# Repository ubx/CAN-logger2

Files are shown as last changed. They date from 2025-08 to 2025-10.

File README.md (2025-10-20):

# ESP32 CAN Logger for CANaerospace with WiFi File Browser

This project implements a **dual-mode ESP32 application** for capturing and storing CAN bus data onto an SD card, \
while also providing a temporary WiFi access point with a web-based file browser to retrieve logged data.

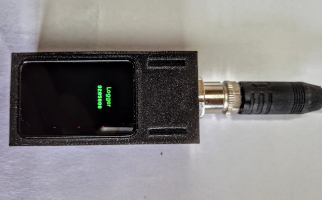
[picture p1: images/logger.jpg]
Logger CAN Logger

---

## Features

### WiFi File Browser
- **WiFi SoftAP Setup** with WPA/WPA2 authentication.
- **Dynamic SSID Generation** based on ESP32 MAC address.
- **Web-based File Browser**:
  - Displays SD card files in a clean HTML table.
  - Supports file size display in human-readable format (KB, MB, GB).
  - Click-to-download functionality with MIME type detection.
- **Automatic Session Timeout**
  - Tracks last HTTP activity.
  - Shuts down after configurable inactivity time.
---

### CAN Logging System
- **CAN Bus Support (TWAI Driver)**
  - Configured for **500 kbit/s**.
  - Accepts all CAN frames.
  - Reliable driver startup with retry on failure.
- **SD Card Logging**
  - Files named sequentially as `CANxxxxx.LOG`.
  - Automatic **old file cleanup** if free space < 2 GB (reclaims up to 4 GB).
  - Efficient batch writes with **32 KB buffering**.
  - Uses `fsync()` to ensure data integrity.
- **Logging Format**
  - Each CAN frame stored as:
    ```
    (timestamp) can <ID>#<DATA>
    ```  
    Example:
    ```
    (1755839938.123456) can 123#11AAFF
    ```
- **Task-based Architecture**
  - `CAN_RX Task`: Receives frames from TWAI driver.
  - `CAN_Proc Task`: Formats messages into log lines.
  - `SD_Writer Task`: Buffers and writes batches to SD card.
- **Runtime Monitoring**
  - Tracks total message count.
  - Periodic logging of statistics to console.

---

## Technical Highlights
- **FreeRTOS Queues** for decoupled CAN reception and SD writing.
- **High-throughput SD logging** using buffered I/O.
- **Failsafe Storage Management** with automatic cleanup.
- **Lightweight Web Server** (ESP-IDF HTTPD) for SD browsing and downloads.
- **No RTC dependency**: Uses a fictional start timestamp to emulate Unix time.
- **Tested on an ESP32-S3 board:** [ESP32-S3 1.64inch AMOLED Touch Display Development Board](https://www.waveshare.com/esp32-s3-touch-amoled-1.64.htm) with a SANDISK Ultra \
  64 GB, microSDXC, U1, UHS-I.
- **Performance Test**: Running `cangen can0 -D i -I i -L 4 -g 0.5` resulted in a transmission rate of \
approximately 1,800 messages per second.
- **Power consumption**: Web server: 473 mW; Logger with display on: 420 mW; Logger with display off: 440 mW.
---

## Typical Use Case
1. **Power up device** → ESP32 starts in **WiFi AP mode** with SD card accessible via browser.
2. **Download / inspect past CAN logs** through the web interface.
3. **After inactivity timeout** → Device switches into **logging mode**, continuously recording
4. CAN traffic onto the SD card.

---

## Pin-to-Pin Wiring Table

| ESP32 Pin | Function | Connected To | Notes |
|---|---|---|---|
| GPIO1 | SPI MOSI | SD Card MOSI | Data out from ESP32 → SD |
| GPIO3 | SPI MISO | SD Card MISO | Data in from SD → ESP32 |
| GPIO2 | SPI SCLK | SD Card SCLK | SPI clock |
| GPIO41 | SPI CS | SD Card CS | Chip select |
| GPIO9 | CS | LCD Chip Select | Active low |
| GPIO10 | PCLK | LCD SPI Clock / Pixel Clock | QSPI clock |
| GPIO11 | DATA0 | LCD Data 0 (D0) | QSPI data line |
| GPIO12 | DATA1 | LCD Data 1 (D1) | QSPI data line |
| GPIO13 | DATA2 | LCD Data 2 (D2) | QSPI data line |
| GPIO14 | DATA3 | LCD Data 3 (D3) | QSPI data line |
| GPIO21 | RST | LCD Reset | Optional, active low 
| GPIO18 | CAN TX | CAN Transceiver TXD | Transmit to CAN bus |
| GPIO17 | CAN RX | CAN Transceiver RXD | Receive from CAN bus |
| 3V3 | Power | SD Card VCC, CAN VCC | Ensure 3.3V compatible |
| GND | Ground | SD Card GND, CAN GND | Common ground reference |
| CANH/— | — | CAN Bus High Line | Differential bus line |
| CANL/— | — | CAN Bus Low Line | Differential bus line |

## Recommended Parts List

### Core Components
- **ESP32 Development Board**
  - Example: ESP32-DevKitC, ESP32-WROOM, or M5Stack Core (if display/UI desired)
  - Must expose SPI pins and GPIOs used in the project

- **SD Card Module (SPI interface)**
  - Example: MicroSD Card Module (3.3V logic, SPI mode support)
  - Ensure 3.3V compatible (no 5V modules without level shifting)
  - MicroSD card, Class 10, A1 or higher, ≥16 GB recommended

- **CAN Transceiver** (connects ESP32 to CAN bus)
  - Example ICs:
    - SN65HVD230 (3.3V, commonly used with ESP32)
    - MCP2551 (5V, requires level shifting for ESP32)
    - TJA1050 (5V, also requires level shifting)
  - Choose based on bus voltage (3.3V-friendly parts are easier)

### Power & Connectivity
- **Stable 5V Supply** (for ESP32 board)
  - ESP32 boards usually regulate down to 3.3V internally
- **Common Ground Reference** between ESP32, SD card, and CAN transceiver
- **CAN Bus Wiring**
  - Twisted pair cable (for CANH & CANL)
  - 120 Ω termination resistors at both bus ends

### Optional / Helpful
- **MicroSD Card Reader** (for PC, to inspect logs directly if needed)
- **USB-to-CAN Adapter** (for testing/logging against a PC CAN interface)
- **Case/Enclosure** to protect the ESP32 + modules in automotive environment
- **For CANaerospace logs**: use [this program](https://github.com/ubx/canlog-correct-ts/blob/master/correct-ts.py) to adjust timestamps.
- **Format SD card**: use [this tool](https://www.sdcard.org/downloads/sd-memory-card-formatter-for-linux/)

### Bill of materials

| Number | Part | Qty | Picture | 	Source |
|---|---|-----|---|---|
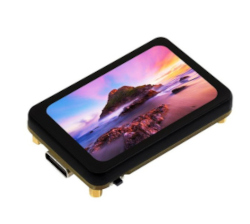
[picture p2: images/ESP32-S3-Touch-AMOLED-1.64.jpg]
| 1 | ESP32-S3 1.64inch AMOLED<br/> Touch Display Development Board | 1 |   | [AMOLED Touch Display<br/>Development Board](https://www.waveshare.com/esp32-s3-touch-amoled-1.64.htm) | 
| 2 | SN65HVD230 CAN Board | 1 | Board | [SN65HVD230 CAN Board	](https://www.waveshare.com/sn65hvd230-can-board.htm) | |
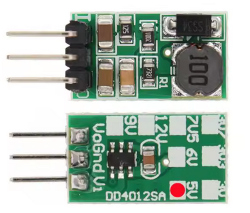
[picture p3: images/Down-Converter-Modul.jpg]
| 3 | Step Down Converter Modul | 1 |  | [Step Down Converter Modul	](https://de.aliexpress.com/item/1005006461126809.html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) |
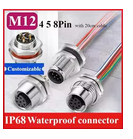
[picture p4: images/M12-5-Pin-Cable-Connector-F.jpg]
| 4 | M12 5 Pin Cable Connector | 1 |  | [M12 5 Pin Cable Connector](https://de.aliexpress.com/item/1005008983446794.html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)  |
| 5 | micro sd card | 1 | Board |
| 6 | M2x5 round screw | 4 | | |
| 7 | M2.5x5 countersunk screw | 1 |
| 8 | M2.5x4 insert | 1 |
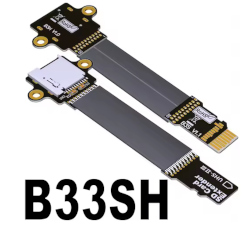
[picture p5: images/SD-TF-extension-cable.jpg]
| 9 | Optional:<br/>SD-TF-extension-cable | 1 |  | [SD-TF-extension-cable	](https://de.aliexpress.com/item/1005005671622003.html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) |

---

## Troubleshooting: sdQueue full / canQueue full warnings
If you see warnings like:
- W (xxxx) CAN_Proc: sdQueue full, dropped line
- W (xxxx) CAN_RX: canQueue full, dropped

it means the producer tasks (CAN reception/formatting) are temporarily faster than the consumer (SD writer). \
The firmware includes several mitigations:

Additional steps you can take
- Use a fast SD card (A1/A2 or High Endurance) and keep it healthy/formatted (FAT32).
- Reduce other workload while logging (disable unnecessary peripherals, WiFi, or display if not needed).
- If you still experience drops, you can increase queue depths in src/logger/logging.cpp:
  - CAN_QUEUE_LEN: number of CAN frame buffered between driver and formatter.
  - SD_QUEUE_LEN: number of formatted lines buffered before SD writing.
    Be mindful that increasing these consumes internal RAM.
- If your board has PSRAM, keep it enabled. The logger uses a large batch buffer to write in big chunks for higher throughput.
- Ensure stable 3.3 V supply. Brownouts can slow peripherals and the filesystem.

Notes
- Even with a high-rate CAN traffic (e.g., ~1200 msgs/s), a proper SD card and power supply should avoid drops in most cases.
- If absolute losslessness is required, consider reducing CAN bus load, increasing queue sizes, or writing in binary \
to reduce per-message overhead.

## Todo
- Check display z-distance.
- PCB, move modules up 2mm z-distance.
- PCB, bigger holes for CAN connector cables.
- Check usb hole, make it more tolerant.
- Better lid locking.

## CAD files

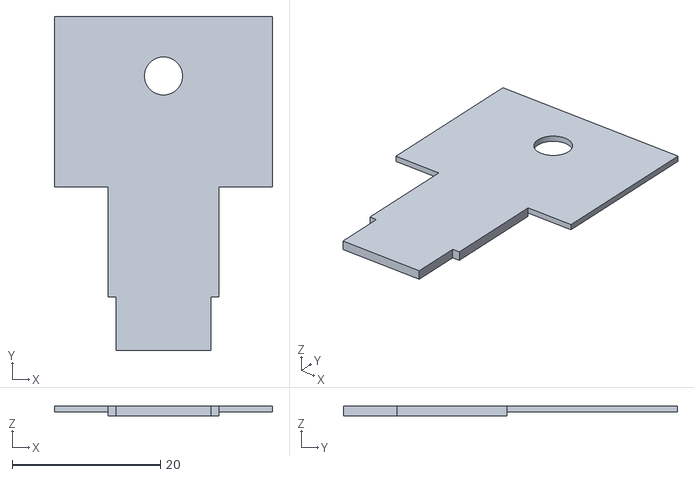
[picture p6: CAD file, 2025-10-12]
case/lid-sdcard-negative-3.stl
29.4 x 45.0 x 1.30

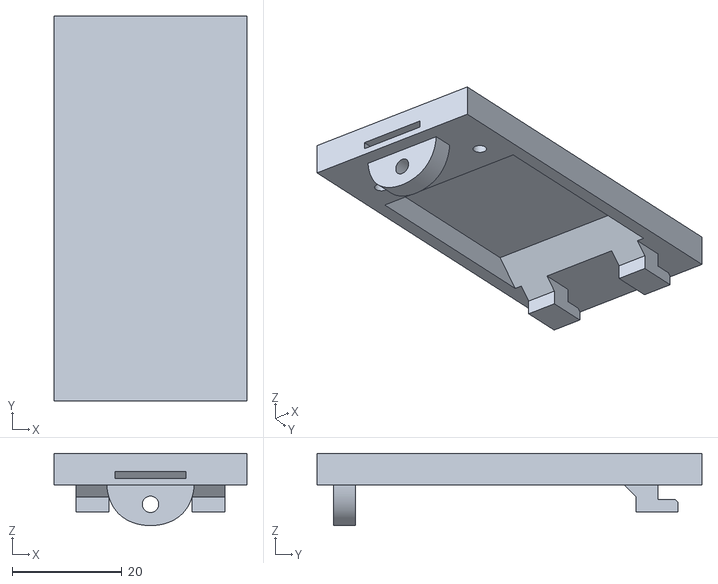
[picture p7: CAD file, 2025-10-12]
case/lid-sdcard.stl
35.1 x 70.2 x 13.2

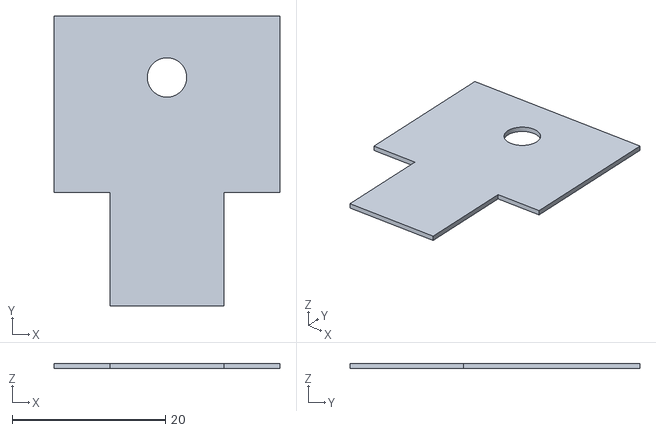
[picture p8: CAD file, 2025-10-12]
case/lid-sdcard-negative-2.stl
29.4 x 37.8 x 0.7

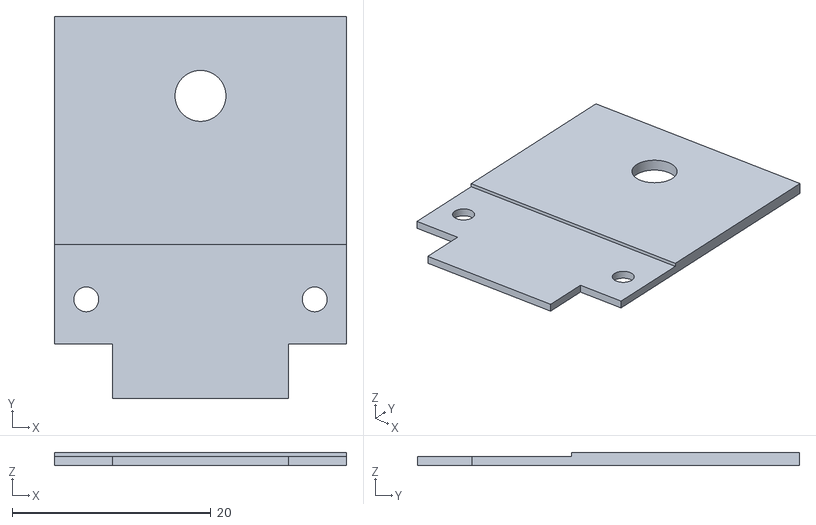
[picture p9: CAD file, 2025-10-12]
case/lid-sdcard-negative-1.stl
29.4 x 38.5 x 1.30

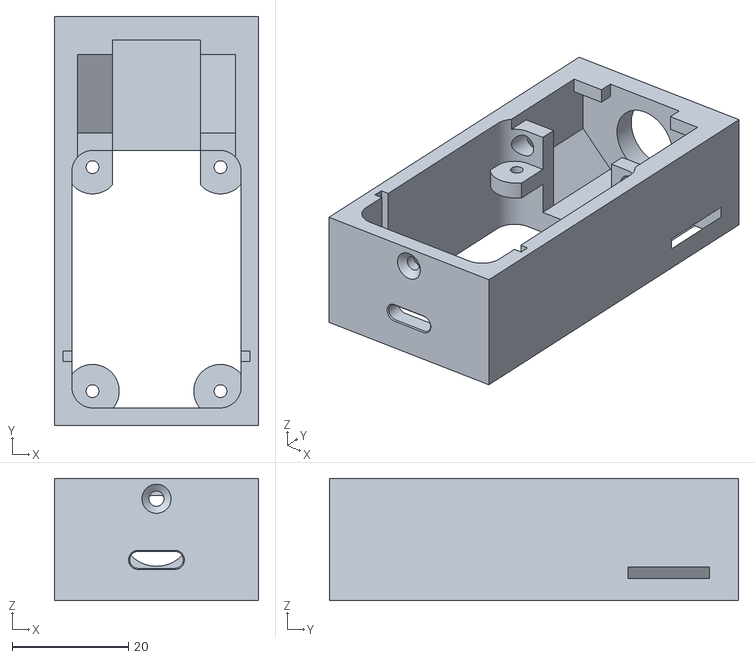
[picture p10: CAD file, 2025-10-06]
case/case.stl
35.1 x 70.3 x 21.0

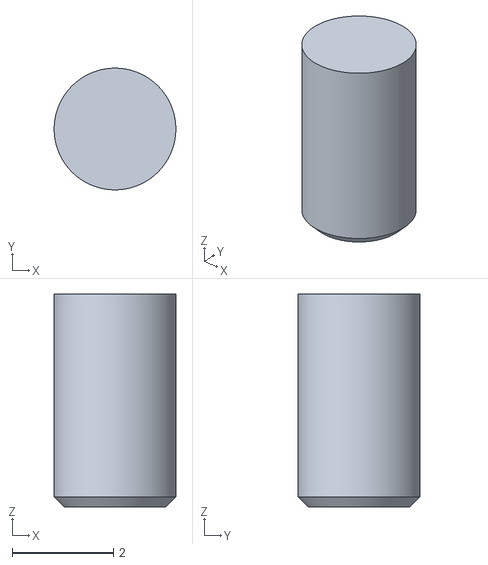
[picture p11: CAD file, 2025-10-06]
case/cones.stl
2.40 x 2.40 x 4.20

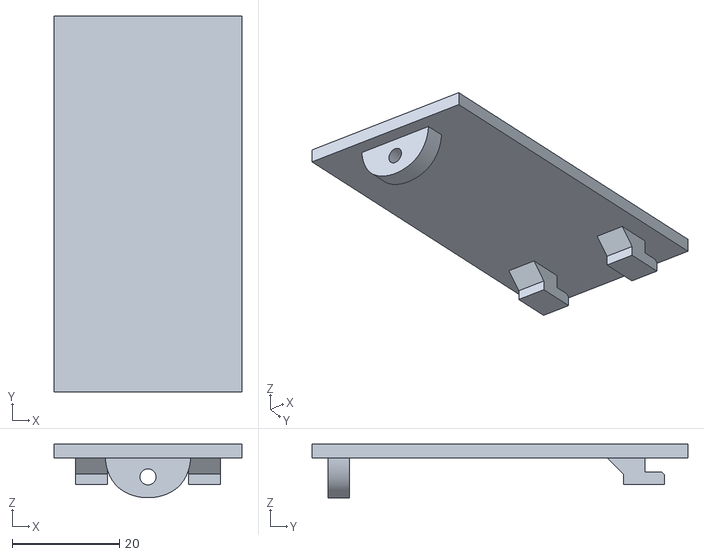
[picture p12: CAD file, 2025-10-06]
case/lid.stl
35.1 x 70.2 x 10.00

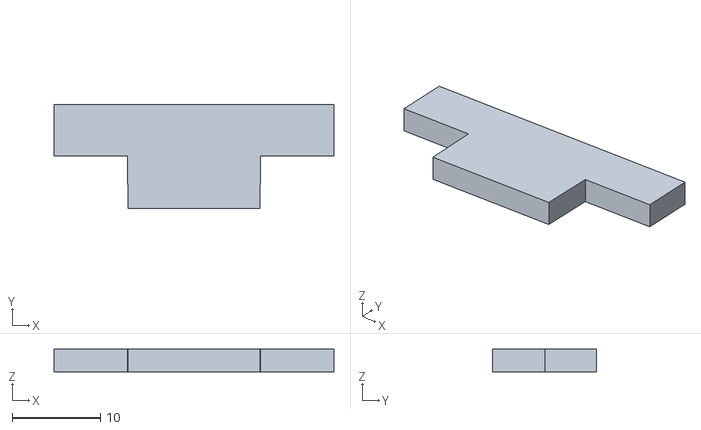
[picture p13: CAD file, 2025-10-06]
case/lid-sdcard-negative-4.stl
31.8 x 11.8 x 2.60

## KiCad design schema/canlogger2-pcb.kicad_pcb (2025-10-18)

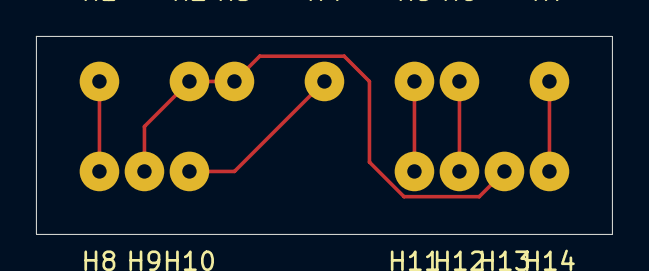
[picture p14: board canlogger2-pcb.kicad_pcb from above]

Board: 2 copper layers, 32.0 x 11.0 mm, 14 parts (0 on the bottom side), 6 nets.

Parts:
H1: 5V; ConnectingHole_0.8mm_M2_DIN965_Pad
H2, H3, H9, H13: GND; ConnectingHole_0.8mm_M2_DIN965_Pad
H4: 12V; ConnectingHole_0.8mm_M2_DIN965_Pad
H5: Tx; ConnectingHole_0.8mm_M2_DIN965_Pad
H6: Rx; ConnectingHole_0.8mm_M2_DIN965_Pad
H7, H14: 3.3V; ConnectingHole_0.8mm_M2_DIN965_Pad
H8: Vo; ConnectingHole_0.8mm_M2_DIN965_Pad
H10: Vi; ConnectingHole_0.8mm_M2_DIN965_Pad
H11: TX; ConnectingHole_0.8mm_M2_DIN965_Pad
H12: RX; ConnectingHole_0.8mm_M2_DIN965_Pad

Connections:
unnamed: H1.1, H8.1
unnamed: H4.1, H10.1
unnamed: H5.1, H11.1
unnamed: H6.1, H12.1
unnamed: H2.1, H3.1, H9.1, H13.1
unnamed: H7.1, H14.1

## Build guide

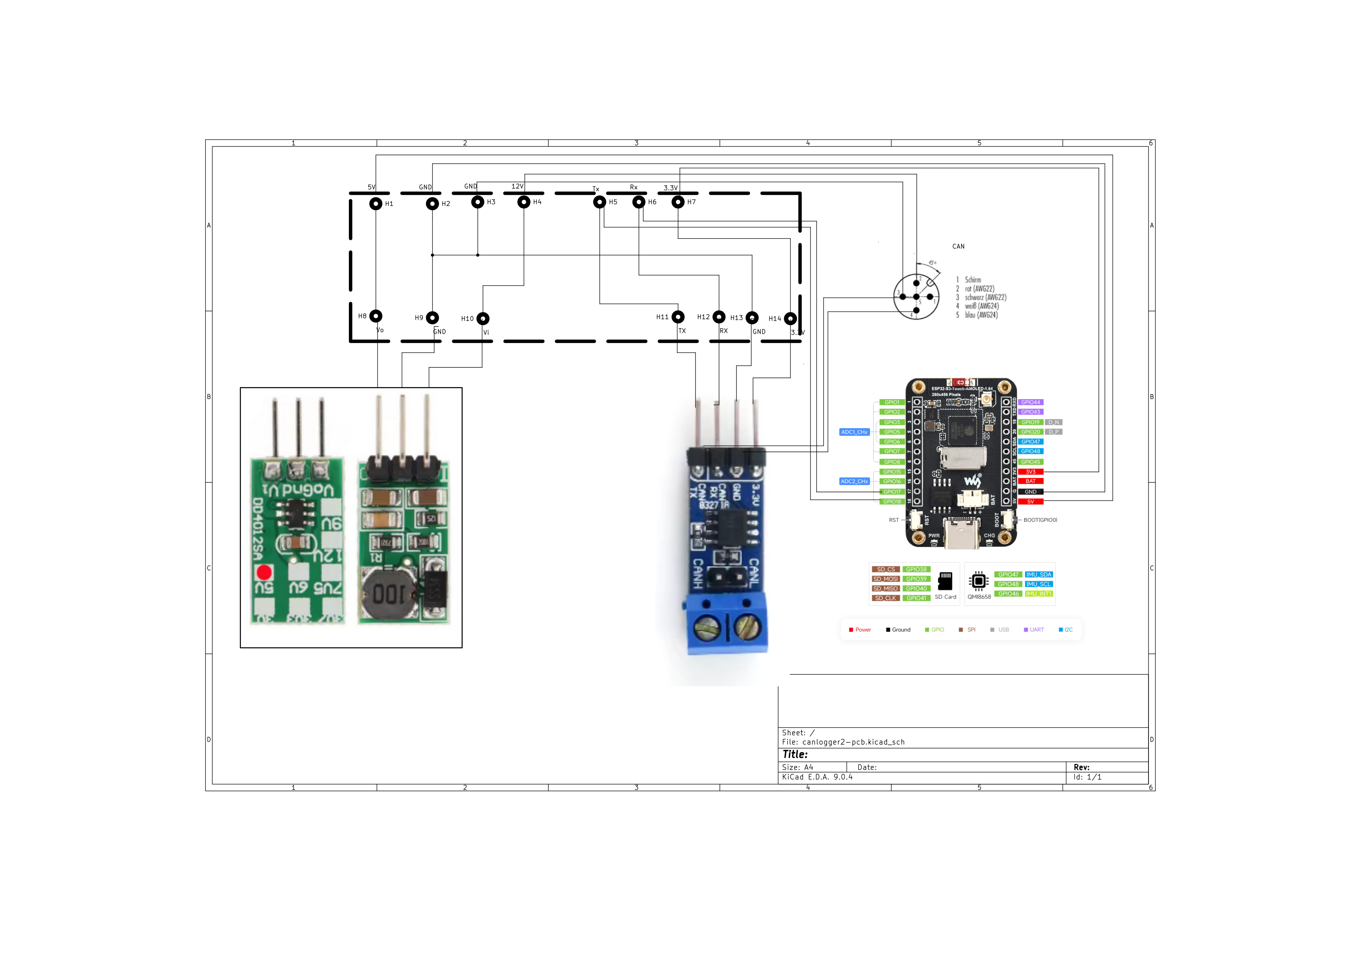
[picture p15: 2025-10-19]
schema/wiring.png

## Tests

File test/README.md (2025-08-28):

# CAN Log Checker

This Python tool validates CAN bus logs generated with `'cangen can0 -D i -I i -L 4 -g 10'` and recorded in `candump`-style format:

## Features
- Parses `candump`-style log files.
- Starts from the first CAN ID found in the log.
- Verifies sequential CAN ID increments (with wrap at `0x7FF`).
- Detects missing frames and corrupted IDs.
- Prints per-line issues and a final summary with statistics.

## Examples of supported formats:
```
(1756343254.078218) can0 36B#6BA30700
(1756343254.078218) can 36B#6BA30700
(1756343254.078218) vcan 36B#6BA30700
```
## Usage
Run the checker on a log file:

```bash
python check_canlog.py <logfile>

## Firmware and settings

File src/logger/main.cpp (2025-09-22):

#include <esp_event.h>
#include <esp_heap_caps.h>
#include <esp_log.h>
#include <esp_netif.h>
#include <esp_system.h>
#include <esp_timer.h>
#include <esp_wifi.h>
#include <nvs_flash.h>

#include "gui.h"
#include "wifi_web.h"
#include "logging.h"
#include "spi.h"

#ifndef APP_NAME
#define APP_NAME "UnknownApp"
#endif

#ifndef APP_VERSION
#define APP_VERSION "0.0.0"
#endif

#ifndef GIT_REVISION
#define GIT_REVISION "unknown"
#endif

static const unsigned IDLE_TIME = 3 * 60 * 1000;
static const char* TAG = "CAN_Logger";

static const unsigned display_on_time_sec = 5 * 60;

// === Counter Task ===
static void display_message_counter(void* arg)
{
    ESP_LOGI(TAG, "Starting display_message_counter task for %u seconds", display_on_time_sec);

    unsigned cnt = 0;
    while (cnt++ < display_on_time_sec)
    {
        set_label2(get_message_count());
        vTaskDelay(pdMS_TO_TICKS(1000));
    }
    turn_display_off();    // to avoid burn-in risk
    vTaskDelete(nullptr);  // safely end this task
}

extern "C" void app_main(void)
{
    vTaskDelay(pdMS_TO_TICKS(1000));
    ESP_LOGI(TAG, "\n=== %s Info ====", TAG);
    ESP_LOGI(TAG, "App: %s", APP_NAME);
    ESP_LOGI(TAG, "Version: %s", APP_VERSION);
    ESP_LOGI(TAG, "Git Rev: %s", GIT_REVISION);
    ESP_LOGI(TAG, "ESP-IDF Version: %s", esp_get_idf_version());

    size_t psram_size = heap_caps_get_total_size(MALLOC_CAP_SPIRAM);
    size_t psram_free = heap_caps_get_free_size(MALLOC_CAP_SPIRAM);
    if (psram_size > 0)
    {
        ESP_LOGI(TAG, "PSRAM detected");
        ESP_LOGI(TAG, "Total PSRAM: %u bytes", (unsigned)psram_size);
        ESP_LOGI(TAG, "Free PSRAM:  %u bytes", (unsigned)psram_free);
    }
    // Init NVS
    esp_err_t ret = nvs_flash_init();
    if (ret == ESP_ERR_NVS_NO_FREE_PAGES || ret == ESP_ERR_NVS_NEW_VERSION_FOUND)
    {
        ESP_ERROR_CHECK(nvs_flash_erase());
        ret = nvs_flash_init();
    }
    ESP_ERROR_CHECK(ret);
    ESP_ERROR_CHECK(esp_netif_init());
    ESP_ERROR_CHECK(esp_event_loop_create_default());

    spi_init();
    gui_init();

    // show name and version
    set_label1(APP_NAME);
    set_label2(APP_VERSION);
    vTaskDelay(pdMS_TO_TICKS(5000));

    mount_sdcard();

    // WiFi Phase
    wifi_init_softap();
    set_label1("AP");
    set_label2(get_ip_address());
    httpd_handle_t server = start_webserver();
    reset_web_activity();
    while (true)
    {
        if (esp_timer_get_time() / 1000ULL - get_last_web_activity() >= IDLE_TIME)
        {
            break;
        }
        vTaskDelay(pdMS_TO_TICKS(1000));
    }
    if (server) httpd_stop(server);
    esp_wifi_stop();

    // Logging Mode
    set_label1("Logger");
    xTaskCreate(display_message_counter, "Counter", 4096, nullptr, 2, nullptr);
    start_logging_mode();
}

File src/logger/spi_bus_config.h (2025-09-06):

#pragma once

#define MOSI_IO_NUM GPIO_NUM_39
#define MISO_IO_NUM GPIO_NUM_40
#define SCLK_IO_NUM GPIO_NUM_41
#define GPIO_CS GPIO_NUM_38

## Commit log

2025-08-28 Update tested board link.
2025-08-28 Print Can Id with leading zeros.
2025-09-06 Change spi config.
    New board is https://www.waveshare.com/esp32-s3-touch-amoled-1.64.htm
    Old was https://www.waveshare.com/wiki/ESP32-S3-Touch-AMOLED-1.75
2025-09-07 Set board flash and psram size.
2025-09-08 Add LVGL stuff, wip.
    [partitions.csv]
2025-09-11 Add case.
    [CAN-Logger-Case-lit.stl, CAN-Logger-Case.stl]
2025-09-16 Runs, but nothing is displayed!
    [partitions.csv]
2025-09-17 Rework, works, but no info displayed.
    [common.h, main.cpp, spi.cpp]
2025-09-17 Rework, works and info displayed!
    [common.h, main.cpp, sdcard.cpp]
2025-09-21 Update readme.
    [CAN-Logger-Case-lid.stl]
2025-09-22 Turn off display after 5 min. logging to avoid burn-in risk. Bump version.
    [main.cpp]
2025-09-26 Add housing lid with sd card.
    [CAN-Logger-Case-lid-with-sdcard.stl]
2025-09-26 Update power consumption and BOM.
2025-10-06 Update bom.
2025-10-06 Add new 3d housing files.
    [CAN-Logger-Case-lid-with-sdcard.stl, CAN-Logger-Case-lid.stl, CAN-Logger-Case.stl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]
2025-10-12 Update housing files.
    [lid-sdcard-negative-1.stl, lid-sdcard-negative-2.stl, lid-sdcard-negative-3.stl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]
2025-10-12 Small change of sd card position and size.
    [lid-sdcard-negative-1.stl, lid-sdcard-negative-2.stl, lid-sdcard-negative-3.stl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]
2025-10-18 Add pcb and wiring.
    [canlogger2-pcb.step]
2025-10-19 New wiring diagram, add todo.
